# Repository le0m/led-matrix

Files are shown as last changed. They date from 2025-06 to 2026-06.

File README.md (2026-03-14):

This is a personal project to control a LED matrix from an ESP32 microcontroller.

<table>
    <tr>
        <td>
            <p>Font</p>
            Front
        </td>
        <td>
            <p>Back</p>
            Back
        </td>
        <td>
            <p>Inside overview</p>
            Inside overview
        </td>
    </tr>
    <tr>
        <td>
            <p>GY-521 glued to the inner border of the panel frame</p>
            GY-521 glued to the inner border of the panel frame
        </td>
        <td>
            <p>ESP32 wires</p>
            ESP32 wires
        </td>
        <td>
            <p>Under the LED panel</p>
            Under the LED panel
        </td>
    </tr>
    <tr>
        <td>
            <p>Image rendering</p>
            Image rendering
        </td>
        <td>
            <p>GIF rendering</p>
            GIF rendering
        </td>
        <td>
            <p>Rotation</p>
            Rotation
        </td>
    </tr>
</table>

Some LEDs have been harmed in the development process. Our thoughts go to all the dead pixels out there~

# Components

My LED panel is 19,2x19,2cm, so I'm using a 25x25x3cm frame with a 3D-printed passepartout. I've screwed 4 screws through the frame's backpanel into the LED panel's screw holes, with spacers to keep the panel away from the backpanel and pressed against the glass frame.

The gyroscope is glued inside with the chip facing upwards (on the inner border of the frame), while the esp32 and the wires are free-moving (but not too much since it's packed in there) behind the LED panel :D

For powering it I'm using a random USB charger (5V 3A output): I've cut the mini-USB head and wired the esp32 board and LED panel (plus the gyroscope's ground because the esp32's were full). The panel actually uses up to 4-5A (depending on "brand", size and brightness) and the esp32 uses 0.5-1A, so I'm looking for a small power supply that can accomodate that, but it's currently working so ¯\\_(ツ)_/¯

Wiring/PIN layout

Wiring/PIN layout

## Hardware

- an ESP32 board/kit (ex. AZ-Delivery's [ESP32 Dev KitC v2](https://www.az-delivery.de/en/products/esp32-developmentboard))
- a HUB-75/HUB-75E RGB LED matrix (ex. [this](https://www.waveshare.com/wiki/RGB-Matrix-P3-64x64) one, I'm using off-brand ones from AliExpress)
- an MPU6050 3-axis gyroscope + accelerator (ex. AZ-Delivery's [GY-521](https://www.az-delivery.de/en/products/gy-521-6-achsen-gyroskop-und-beschleunigungssensor))
- a display frame to put everything in (the passepartout model is in `led-matrix-passepartout.stl`)

## Software

- [AdafruitGFX](https://github.com/adafruit/Adafruit-GFX-Library), as a requirement of other libraries for rendering
- [ESP32-HUB75-MatrixPanel-DMA](https://github.com/mrcodetastic/ESP32-HUB75-MatrixPanel-DMA), for controlling the LED matrix
- [FastLED](https://github.com/FastLED/FastLED), for color conversion functions and other utilities
- the ESP32Async project and their [AsyncTCP](https://github.com/ESP32Async/AsyncTCP)/[ESPAsyncWebServer](https://github.com/ESP32Async/ESPAsyncWebServer) libraries
- [ArduinoJSON](https://github.com/bblanchon/ArduinoJson), for JSON de/serialization
- [AnimatedGIF](https://github.com/bitbank2/AnimatedGIF) and [JPEGDEC](https://github.com/bitbank2/JPEGDEC), for decoding GIFs and JPEGs
- project Nayuki's [qr-code-generator](https://github.com/nayuki/QR-Code-generator), for generating QR codes (included in `lib/` directory)
- [i2cdevlib](https://github.com/jrowberg/i2cdevlib), for reading the MPU6050 sensor (included in `lib/` directory)
- [NES.css](https://github.com/nostalgic-css/NES.css), for the NES-styled theme

Thanks to all of them :)

## Note on PlatformIO

PlatformioIO does not update espressif in their releases, and currently (`platformio/platform-espressif32 @ 6.10.0`) uses version `2.0.17` (see github discussion [here](https://github.com/platformio/platform-espressif32/issues/1225#issuecomment-2245116163)).

If a newer version is really needed, use the [pioarduino](https://github.com/pioarduino/platform-espressif32) fork for espressif 3+. I tried it to have [this](https://github.com/espressif/arduino-esp32/pull/10217) fix, but switching caused the firmware bin to go from ~1 MB to ~1.2 MB.
This is why the `pathExists()` method exists.

# Usage

On first boot the esp32 creates a WiFi network with name `esp32-led-matrix` and password `daftpunk` (hardcoded in `src/wifi.h`). Connect to it, turn the frame upside down and scan the QR code to visit the web UI, where the WiFi SSID and password can be configured (stored in plain JSON in the flash memory). The esp32 will then connect to the provided WiFi and show a different QR code to visit the web UI on that network.

## Display modes

The LED panel has 4 display modes, depending on the frame orientation:
- ↑ shows image or GIF uploaded through the web UI
- → shows a [Conway's Game of Life](https://en.wikipedia.org/wiki/Conway's_Game_of_Life) game
- ↓ shows the QR code
- ← shows a position on a map

## Web UI

- WiFi settings
- brightness (0-255)
- upload image or GIF, with preview of the scaled-down version; this file will be stored in the flash memory and loaded on boot, so the size is limited depending on the model of esp32 used (mine has 1.4MB and I'm reserving some for the project's static data)
- map settings (upload map image, set position, use remote API)
- upload firmware updates (OTA)
- application logs (by default the logs are sent only if the web UI is loaded by at least 1 user, use the compile variable `LOG_QUEUE` to enable a queue of up to 50 messages that will be delivered once a user connects)
- resource usage and system info

# TODOs

- add FPS and other Life config
- music visualizer (needs mic)
- setting for map remote API pull time (15m, 30m, 1h)
- map:
    - zoom (need scaling on esp32)
    - other position centering methods (center on point, use a margin to move the view before the position reaches the panel border, ...)
    - store previous positions and show route

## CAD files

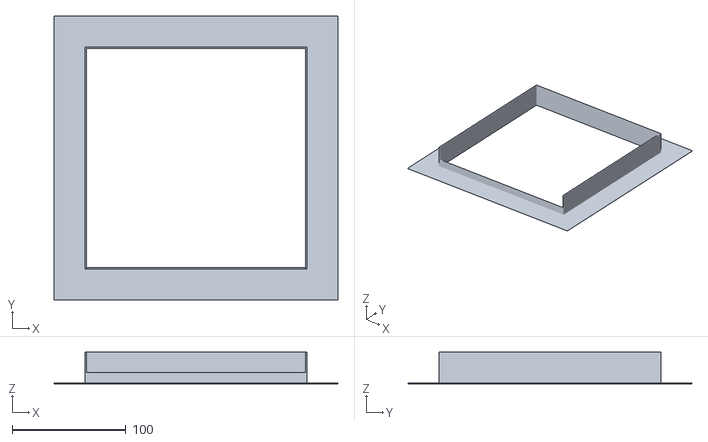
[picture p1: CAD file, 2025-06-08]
led-matrix-passepartout.stl
250.0 x 250.0 x 28.0

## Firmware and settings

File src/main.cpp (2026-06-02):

#include "main.h"

HUB75_I2S_CFG::i2s_pins pins = {R1_PIN, G1_PIN, B1_PIN, R2_PIN, G2_PIN, B2_PIN, A_PIN, B_PIN, C_PIN, D_PIN, E_PIN, LAT_PIN, OE_PIN, CLK_PIN};
HUB75_I2S_CFG ledConfig(
    WIDTH,                   // matrix width
    HEIGHT,                  // matrix height
    CHAIN,                   // chain length
    pins,                    // GPIO map
    HUB75_I2S_CFG::SHIFTREG, // matrix module chip
    false,                   // DMA double buffer (double RAM)
    I2C_CLK,                 // i2s clock speed
    LAT_BLANKING,            // how many clock cycles to blank before/after LAT change
    true,                    // i2s clock phase (positive/negative edge)
    60,                      // minimum refresh rate
    PIXEL_COLOR_DEPTH_BITS   // color depth
);
MatrixPanel_I2S_DMA *display = nullptr;

bool setupOk = false;
OTA ota(1000);
draw_mode drawMode = DRAW_MODE_NONE;
WiFiController wifi;
Life life(WIDTH, HEIGHT);
Media media(WIDTH, HEIGHT);
Map mapp(WIDTH, HEIGHT);
QRCode qr(WIDTH, HEIGHT);
AsyncWebServer server(80);
ModeSelector selector;
Config conf(updateConfig);
Renderer *currentMode = nullptr;

void updateQrText() {
    const char* url = wifi.getUrl();
    if (url == nullptr) {
        Log::instance()->error("Error getting URL for QR code\n");

        return;
    }

    Log::instance()->info("QR code URL: %s\n", url);
    if (url[0] != '\0' && !qr.setText(url)) {
        Log::instance()->error("Error encoding IP to QR code\n");
    }
};

bool changeMode(draw_mode newMode) {
    if (newMode == drawMode) {
        return false;
    }

    if (currentMode != nullptr) {
        currentMode->close();
    }

    switch (newMode) {
        case DRAW_MODE_LIFE:
            currentMode = &life;
            break;
        case DRAW_MODE_QR:
            currentMode = &qr;
            break;
        case DRAW_MODE_IMAGE:
            currentMode = &media;
            break;
        case DRAW_MODE_MAP:
            currentMode = &mapp;
            break;

        default:
            currentMode = nullptr;
            break;
    }

    if (currentMode != nullptr) {
        currentMode->open();
    }

    drawMode = newMode;
    Log::instance()->info("Changed mode to %d\n", drawMode);
    if (display != nullptr) {
        display->clearScreen();
    }

    if (newMode == DRAW_MODE_QR) {
        updateQrText();
    }

    return true;
};

void updateConfig(JsonDocument& newConfig) {
    String newSsid = newConfig["wifi"]["ssid"].as<String>();
    String newPassword = newConfig["wifi"]["password"].as<String>();
    String currentSsid = conf.current["wifi"]["ssid"].as<String>();
    String currentPassword = conf.current["wifi"]["password"].as<String>();

    if (!newSsid.equals(currentSsid) || !newPassword.equals(currentPassword)) {
        Log::instance()->info("WiFi configuration changed, reconnecting\n");
        wifi.connect(newSsid.c_str(), newPassword.c_str());
    }
    if (display != nullptr && newConfig["panel"]["brightness"].as<uint8_t>() != conf.current["panel"]["brightness"].as<uint8_t>()) {
        Log::instance()->info("Panel brightness changed: %d\n", newConfig["panel"]["brightness"].as<uint8_t>());
        display->setBrightness(newConfig["panel"]["brightness"].as<uint8_t>());
    }
    if (newConfig["log"]["level"].as<uint8_t>() != conf.current["log"]["level"].as<uint8_t>()) {
        Log::instance()->setLevel(newConfig["log"]["level"].as<log_level>());
        Log::instance()->info("Log level changed: %s\n", Log::instance()->stringLevel().c_str());
    }

    mapp.setConfig(newConfig["map"].as<JsonVariantConst>());
};

void setup() {
    Log::instance()->begin(115200);

    // Initialize LittleFS
    if (!LittleFS.begin()) {
        Log::instance()->error("LittleFS error\n");

        return;
    }

    // Read configuration
    conf.load();

    // Configure logs
    Log::instance()->setLevel(conf.current["log"]["level"].as<log_level>());
#ifdef LOG_QUEUE
    Log::instance()->setQueueSize(50);
#endif

    // Initialize LED matrix
    display = setupLED(ledConfig);
    if (display == nullptr) {
        Log::instance()->error("Error setting up LED matrix\n");

        return;
    }
    display->setBrightness(conf.current["panel"]["brightness"].as<uint8_t>());

    // Initialize gyroscope
    if (!selector.init()) {
        return;
    }

    // Initialize WiFi
    String ssid = conf.current["wifi"]["ssid"].as<String>();
    String password = conf.current["wifi"]["password"].as<String>();
    if (!wifi.connect(ssid.c_str(), password.c_str())) {
        return;
    }

    updateQrText();

    // Initialize log WebSocket
    Log::instance()->initServer(&server);

    // Initialize OTA
    ota.initServer(&server);

    // Initialize modules
    media.initServer(&server);
    mapp.initServer(&server);
    mapp.setConfig(conf.current["map"].as<JsonVariantConst>());
    life.setFPS(FPS);
    conf.initServer(&server);

    // Setup server
    server.on("/favicon.ico", HTTP_GET, [](AsyncWebServerRequest *request) {
        request->send(404);
    });
    server.on("/status", HTTP_GET, [&](AsyncWebServerRequest *request) {
        Log::instance()->info("Sending current status\n");
        JsonDocument status;
        status["heap"]["size"] = ESP.getHeapSize();
        status["heap"]["free"] = ESP.getFreeHeap();
        status["heap"]["minFree"] = ESP.getMinFreeHeap();
        status["heap"]["maxFreeBlock"] = ESP.getMaxAllocHeap();
        status["flash"] = ESP.getFlashChipSize();
        status["firmware"]["size"] = ESP.getFreeSketchSpace(); // see: https://github.com/espressif/arduino-esp32/issues/3131
        status["firmware"]["used"] = ESP.getSketchSize();
        status["firmware"]["version"] = VERSION; // defined at build time, see pre_version.py
        status["filesystem"]["size"] = LittleFS.totalBytes();
        status["filesystem"]["used"] = LittleFS.usedBytes();
        status["chip"]["model"] = ESP.getChipModel();
        status["chip"]["revision"] = ESP.getChipRevision();
        status["chip"]["cores"] = ESP.getChipCores();
        status["chip"]["clock"] = ESP.getCpuFreqMHz();
        status["sdk"] = ESP.getSdkVersion();
        AsyncResponseStream *response = request->beginResponseStream("application/json");
        serializeJson(status, *response);
        response->setCode(200);
        request->send(response);
    });
    server.serveStatic("/", LittleFS, "/www/").setDefaultFile("index.html");

    server.begin();
    // Filesystem::tree("/", 0);
    setupOk = true;
};

ulong lastModePoll = 0;

void loop() {
    if (!setupOk) {
        return;
    }

    ota.loop();

    if (millis() - lastModePoll >= 1000) {
        lastModePoll = millis();
        if (changeMode(selector.getMode())) {
            return;
        }
    }

    if (currentMode != nullptr) {
        currentMode->render(display);
    }
};

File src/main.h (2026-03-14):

#ifndef _MAIN_H
#define _MAIN_H

#include <Arduino.h>
#include "modules/log.h"
#include "modules/config.h"
#include "modules/wifi.h"
#include "modules/led.h"
#include "modules/modeselector.h"
#include "modes/media.h"
#include "modes/map.h"
#include "modes/life.h"
#include "modes/qrcode.h"
#include "modules/ota.h"
#include <ArduinoJson.h>

// Pins
#define R1_PIN R1_PIN_DEFAULT
#define G1_PIN G1_PIN_DEFAULT
#define B1_PIN B1_PIN_DEFAULT
#define R2_PIN R2_PIN_DEFAULT
#define G2_PIN G2_PIN_DEFAULT
#define B2_PIN B2_PIN_DEFAULT
#define A_PIN A_PIN_DEFAULT
#define B_PIN 22 // changed, was 19
#define C_PIN C_PIN_DEFAULT
#define D_PIN D_PIN_DEFAULT
#define E_PIN 32 // changed, was -1
#define LAT_PIN LAT_PIN_DEFAULT
#define OE_PIN OE_PIN_DEFAULT
#define CLK_PIN CLK_PIN_DEFAULT

// Matrix
#define WIDTH MATRIX_WIDTH
#define HEIGHT 64 // changed, was 32
#define CHAIN CHAIN_LENGTH
#define ROWS_IN_PARALLEL MATRIX_ROWS_IN_PARALLEL
#define PIXEL_COLOR_DEPTH_BITS 8
#define LAT_BLANKING 2
#define I2C_CLK HUB75_I2S_CFG::HZ_8M

// Config
#define FPS 15

void updateConfig(JsonDocument& newConfig);

#endif

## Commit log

2025-06-08 feat: initial commit
    [led-matrix-passepartout.stl, partitions.csv]
2025-09-14 refactor: replace using an array of RGB bytes with a proper JPEG decoding library, to save on space and a bit of memory
    [main.cpp, main.h]
2025-09-24 chore: increase app partition size
    [partitions.csv]
2025-11-01 refactor: better handling of mode change, fixed a bunch of problems
    [main.cpp]
2025-11-01 fix: mode changing randomly
    [modeselector.cpp]
2025-11-02 chore: minor ArduinoJSON changes
2025-11-15 feat: print FS tree
2026-06-02 fix: some undefined behavior and wrong frees in logs
    [log.cpp]
2026-06-02 fix: guards and string handling
    [main.cpp]
2026-07-12 add support for adafruit matrixportal s3 board
